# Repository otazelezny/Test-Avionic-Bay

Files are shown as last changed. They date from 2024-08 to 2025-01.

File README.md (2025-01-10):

# Test-Avionic-Bay
Avionic bay for testing purposes.

just an general idea how it should looks

Snímek obrazovky 2024-07-30 v 23 39 08

v2 (7/31/2024)

Snímek obrazovky 2024-07-31 v 15 22 22

schematic v1

Snímek obrazovky 2024-07-31 v 19 22 23

schematic partly routed

Snímek obrazovky 2024-07-31 v 20 21 01

V1.2 - To improve
    -   Better routing 
    -   coil - XFL4020-152ML                    DONE
    -   more troughput trough routes
    -   probe pins 
    -   more outputs and systematic desing
    -   40x40 hole pattern
    -   more cabel holes
    -   big ground plane to sheelding
    -   external 5v input for easier control
    -   continuity charge sense
    -   4 pyro channels                         DONE
    -   second IC for redandency
    -   micro-sd
    -   Thermistor 100k
    -   Neopixel output

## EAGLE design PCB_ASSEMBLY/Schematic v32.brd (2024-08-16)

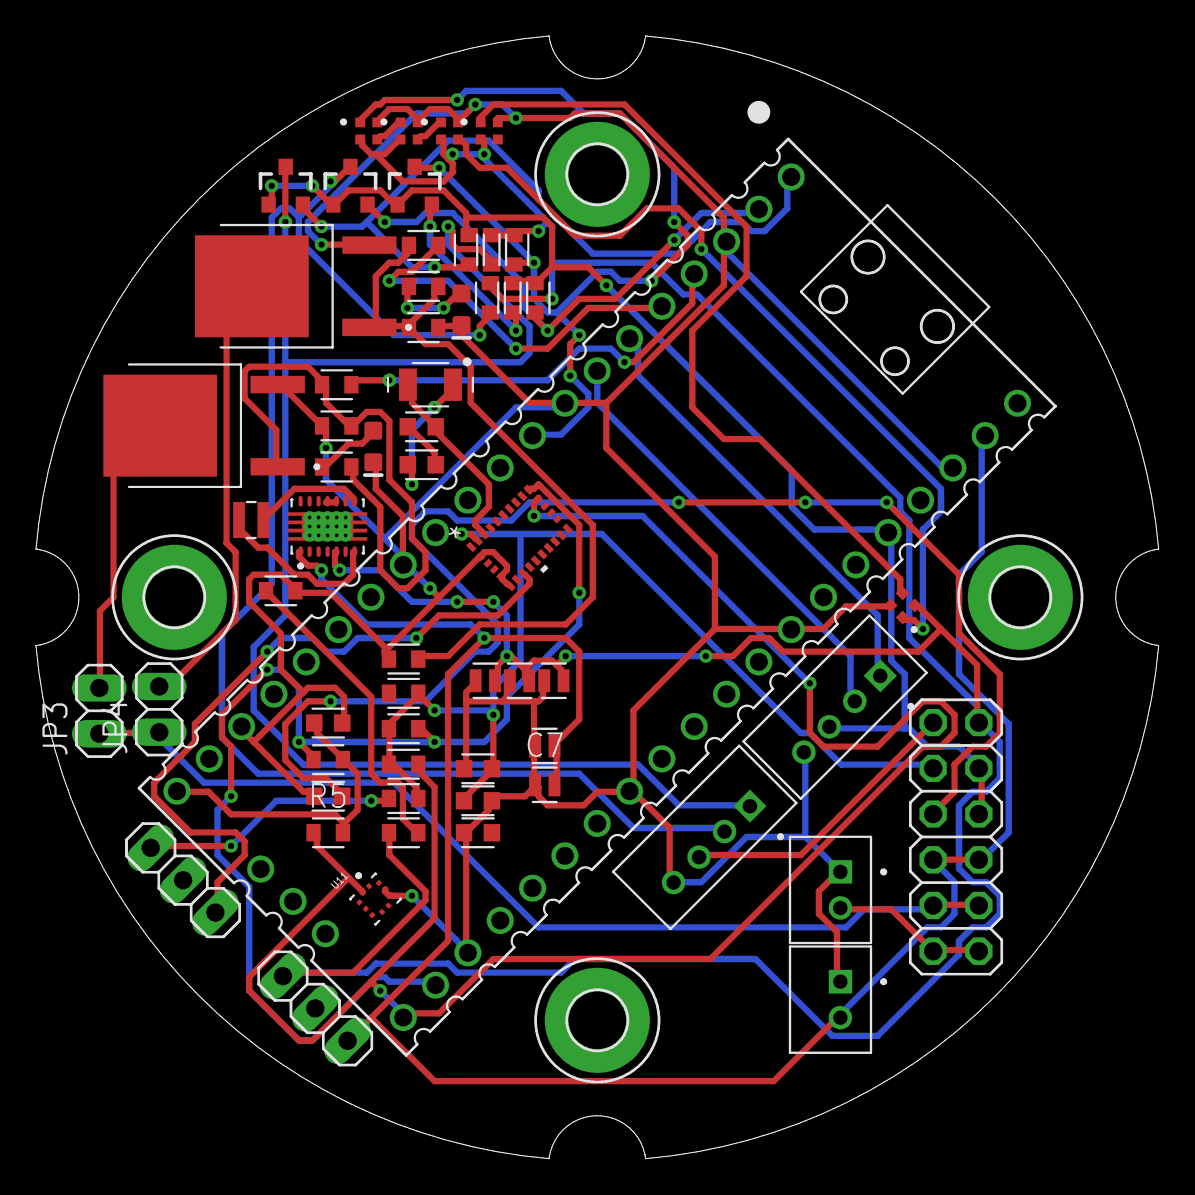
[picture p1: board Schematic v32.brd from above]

Board: 4 copper layers, 62.4 x 62.4 mm, 64 parts (0 on the bottom side), 45 nets.

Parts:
C1: 1μF; CAPC1608X85
C2, C4, C5: 100nF; CAPC1608X85
C3, C11, C12: 120nF; CAPC1608X85
C6: 10n; CAPC1110X102
C7: 100n; CAPC1110X102
C8, C10: 22UF; CAPC1110X102
C9: 22uF; CAPC1110X102
D1, D2: Red; LED-0603
H1, H2, H3, H4: MOUNT-PAD-ROUND3.2; 3,2-PAD
J1, J2: B4B-PH-KL(LF)(SN); JST_B4B-PH-KL(LF)(SN)
J3, J4: B2B-PH-K-S(LF)(SN); JST_B2B-PH-K-S(LF)(SN)
JP1, JP2: PINHD-1X3; 1X03
JP3, JP4: PINHD-1X2; 1X02
JP5: PINHD-2X6; 2X06
L1: 1.5uH; INDUCTOR_2X2
Q1, Q2, Q3: 220mA/50V/3.5Ω; SOT23-3
Q4, Q5: AOD4184A; DPAK228P994X240-4N
R1, R4, R7, R8, R9, R10, R11, R12: 10K; RESC1608X60
R2, R3, R5, R6: 4.7K; RESC1608X60
R13, R14, R15, R16, R17, R18, R19, R20, R21: RESC1608X60
U1: BNO055QFN_BNO055_BOS; QFN_BNO055_BOS
U2: RASPBERRY_PICOTH; PICO-PKG-TH
U3, U4, U5, U6, U7: 4492; LED_4492
U8: TPS63020DSJR; IC_TPS63020DSJR
U11: BMP390L; XDCR_BMP390L
XTAL1: 32.768 kHz; XTAL330X1051X90N

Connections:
BMP390_INT: U2.10, U11.7
BMP390_MODE_SEL: C5.1, R5.2, R6.2, U2.20, U11.1, U11.6
GND: C1.1, C2.1, C3.2, C4.2, C5.2, C6.1, C7.1, C8.1, C9.1, C10.1, D1.C, D2.C, J1.4, J2.4, J3.1, J4.1, Q4.3, Q5.3, R13.1, R16.1, R19.1, R21.2, U1.2, U1.5, U1.6, U1.18, U1.25, U2.3, U2.8, U2.13, U2.18, U2.23, U2.28, U2.33, U2.38, U3.4, U4.4, U5.4, U6.4, U7.4, U8.2, U8.15, U11.3, U11.8, U11.9
HV_DATA_NEOPIXEL: Q3.3, R9.1, U2.9, U3.1
HV_RX_ELRS: J2.1, Q2.3, R8.1
HV_TX_ELRS: J2.2, Q1.3, R10.1
LV_DATA_NEOPIXEL: Q3.2, R11.1
LV_RX_ELRS: Q2.2, R7.1, U2.1
LV_TX_ELRS: Q1.2, R12.1, U2.2
unnamed: C1.2, U1.9
unnamed: R1.1, U1.4
unnamed: L1.P$1, U8.8, U8.9
unnamed: U3.3, U4.1
unnamed: U4.3, U5.1
unnamed: U5.3, U6.1
unnamed: U6.3, U7.1
unnamed: L1.P$2, U8.6, U8.7
unnamed: R14.2, R21.1, U8.3
unnamed: JP1.2, U8.13
unnamed: Q4.1, R15.2, R16.2, R17.1
unnamed: D1.A, R15.1
unnamed: JP3.2, Q4.4
unnamed: Q5.1, R13.2, R18.2, R19.2, R20.1
unnamed: D2.A, R18.1
unnamed: JP4.2, Q5.4
unnamed: C12.1, U1.26, XTAL1.1
unnamed: C11.1, U1.27, XTAL1.2
unnamed: C11.2, C12.2
NRESET: JP2.3, R4.1, U1.11
RX_GPS: J1.1, U2.6
SCL: R3.2, R5.1, U1.19, U2.21, U11.2
SDA: R2.2, R6.1, U1.20, U2.22, U11.4
SWCLK_BNO055: JP2.1, U1.8
SWDIO_BNO055: JP2.2, U1.7
TRIG_CHARGE_1: R17.2, U2.4
TRIG_CHARGE_2: R20.2, U2.5
TX_GPS: J1.2, U2.7
VCC_3_3: J1.3, JP5.4, JP5.6, Q1.1, Q2.1, Q3.1, R7.2, R11.2, R12.2, U2.36
VCC_3_3_BMP390L: C4.1, JP5.5, U11.10
VCC_3_3_BNO055: C2.2, C3.1, JP5.3, R1.2, R2.1, R3.1, R4.2, U1.3, U1.28
VCC_5: C8.2, C9.2, C10.2, JP1.3, JP5.2, R8.2, R9.2, R10.2, R14.1, U3.2, U4.2, U5.2, U6.2, U7.2, U8.4, U8.5
VCC_5_ELRS: J2.3, JP5.1
VCC_CHARGES: JP3.1, JP4.1, JP5.9, JP5.10
VCC_IN: C6.2, C7.2, J3.2, JP1.1, JP5.7, JP5.8, U2.39, U8.1, U8.10, U8.11, U8.12
VCC_IN_CHARGES: J4.2, JP5.11, JP5.12

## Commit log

2024-08-13 pcb lib update
2024-08-13 new ELRS pcb lib
2024-08-14 another version of pcb schema
    [Schematic v9.sch, Schematic_v2.sch, Schematic_v7.sch]
2024-08-14 new version
    [Schematic v13.sch]
2024-08-16 huge update of the pcb
    [Schematic v32.brd]
2024-08-18 Dirextory, new models
    [pcb v2.3mf]

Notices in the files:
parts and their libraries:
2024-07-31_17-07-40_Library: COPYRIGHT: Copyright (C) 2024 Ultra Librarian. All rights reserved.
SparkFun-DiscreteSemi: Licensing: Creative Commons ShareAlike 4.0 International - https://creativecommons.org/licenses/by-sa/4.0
